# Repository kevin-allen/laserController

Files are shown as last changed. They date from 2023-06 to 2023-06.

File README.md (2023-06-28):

# laserController

This repository describes our setup used to perform optogenetic stimulation in behavioral experiments. 

The laser pulses are controlled using a Python script and a TTL signal delivered from an Arduino Uno.

## Material needed

* Arduino Uno
* Arduino Shield (see Eagle files)
* USB cable
* Ethernet cable
* Ethernet socket for the Arduino shield
* Laser head ()
* Laser power ()
* ...

## Arduino shield

The Eagle files of the Arduino sheild are in the folder eagleFiles. You can use these files to generate Gerber files and order the shield from EuroCircuits.
The shield has one Ethernet cable that goes to the laser power box. There are 2 BNC sockets that can be used to send the TTL and power signal to the recording system. The signal will range from 0 to 5V so make sure that the hardware accepting these signals can cope with a 5V signal.

## Installation steps

Ethernet socket:
* pin 2: analog input, set power (0 to 5V defines the ratio of maximum power as defined using the manual poti)
* pin 3: pulse on/off (TTL)
* pin 4 & 5: connect together, apply HIGH for ON, apply LOW for OFF, don't apply any voltage there: key will turn on/off
* pin 6: ground

# Laser controller ROS

These *topics* are subscribed to by the Arduino connected to the Laser controller.

 *   `laser_enable`: bool enabled/disabled
 *   `laser_power`: byte 0-255 relative power of max power set on controller
 *   `laser_pulselen_on`: pulse length [ms] = 1/(2*frequency),  
       duty cycle on [ms] = laser_pulselen_on / (laser_pulselen_on + laser_pulselen_off)
 *   `laser_pulselen_off`: pulse off time [ms], set 0 for constant on

The former (`laser_controller__pulse50dutycycle.old`) sketch only had fixed 50% duty cycle and `laser_pulselen` as corresponding ros topic.

# Usage example
 You can
 - use the example file `python_ros_example/control_laser.py` and set the power, pulse_len and duty_cycle , or
 - use rostopic to publish , see description like in `sketches/laser_controller_ros/laser_controller_ros.ino`
     *   enable: `rostopic pub -1 /laser_enable std_msgs/Bool 1`
     *   set power: `rostopic pub -1 /laser_power std_msgs/UInt8 200`
     *   set pulse len on duration: `rostopic pub -1 /laser_pulselen_on std_msgs/UInt32 5`
     *   set pulse len off duration: `rostopic pub -1 /laser_pulselen_off std_msgs/UInt32 95`

# pulse length, frequency and duty cycle
- $t_\mathrm{on}$: pulse len on duration
- $t_\mathrm{off}$: pulse len off duration
- $T=t_\mathrm{on}+t_\mathrm{off}$: period duration
- $f=\frac{1}{T}$: frequency
- $d = \frac{t_\mathrm{on}}{T}$: duty cycle ( $0 < d \leq 1$ ), <sup><sub>The case `d=1` is treated individually and handled without timers.</sub></sup>

example ( [paper](https://pubmed.ncbi.nlm.nih.gov/35584671/) ):
"stimulation at 10 Hz with a 5 ms duration "
- $f=10\mathrm{Hz},\ T=100\mathrm{ms},\ t_\mathrm{on}=5\mathrm{ms},\ d=0.05$  (this example is acheived by above ros command)

Nota bene: The effective power (measured on average) will scale $\propto d$ as this is the raio of on duration.

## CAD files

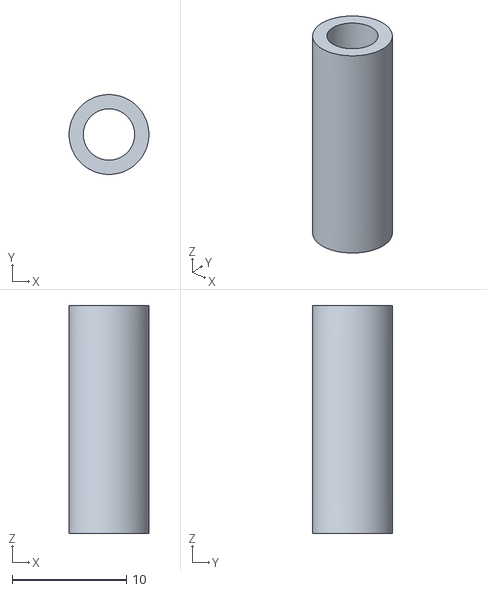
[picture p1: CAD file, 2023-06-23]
Actuator_marcel_edition/spacer.stl
7.00 x 7.00 x 20.0

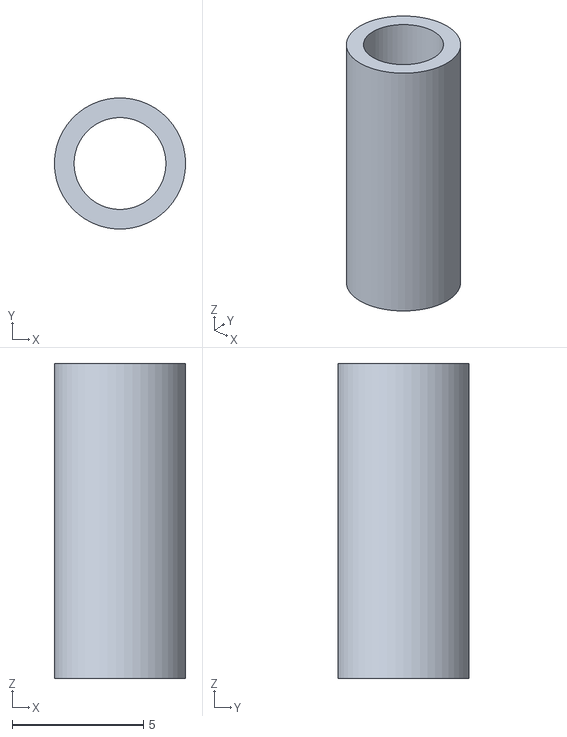
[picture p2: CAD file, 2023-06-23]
actuator_modified/spacer_platforms_12mm.stl
5.00 x 4.99 x 12.0

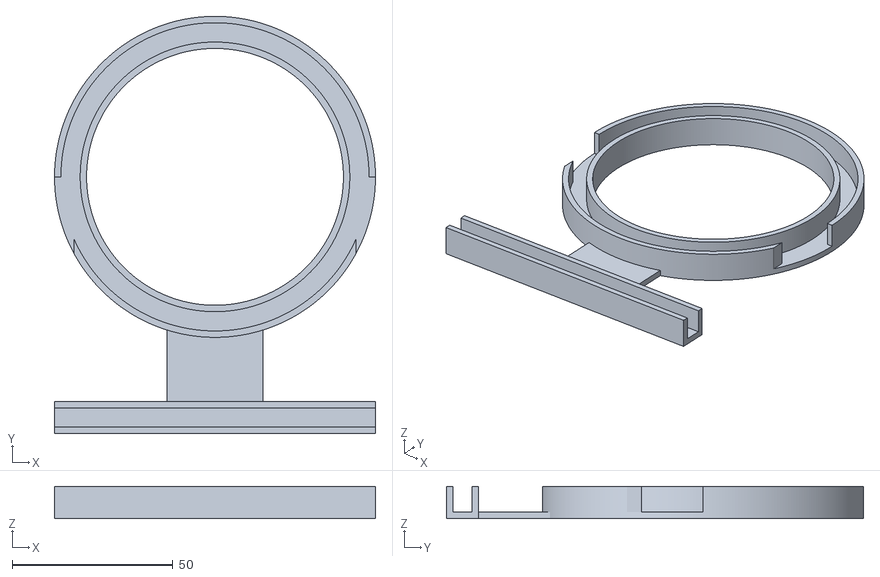
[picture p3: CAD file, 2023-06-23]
cad/splitter_holder_on_actuator.stl
100.0 x 130.0 x 10.0

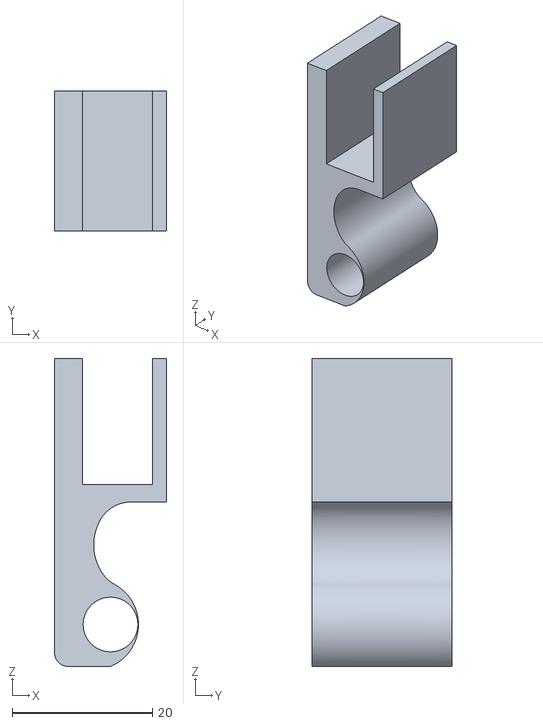
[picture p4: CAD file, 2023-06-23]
Actuator_marcel_edition/ChainHolder.stl
16.0 x 20.0 x 44.0

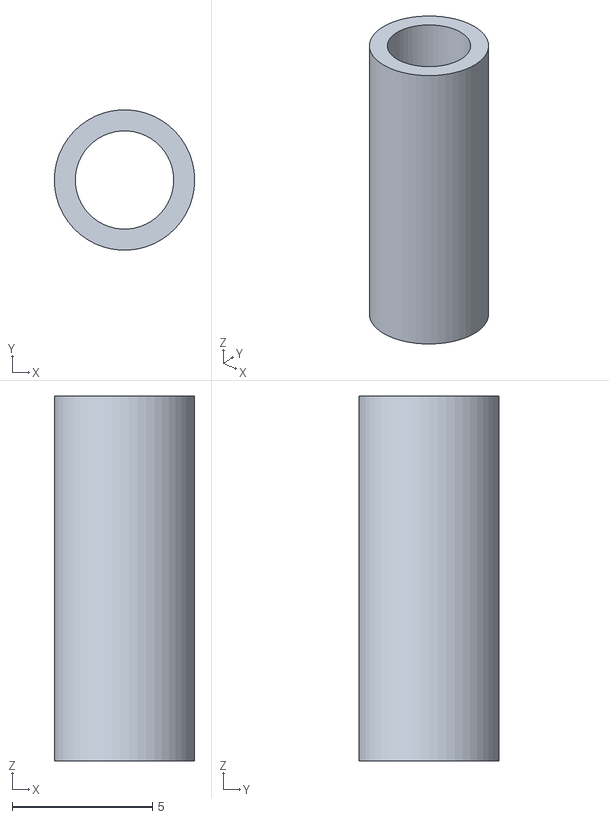
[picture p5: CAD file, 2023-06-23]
actuator_modified/spacer_platforms_13mm.stl
5.00 x 4.99 x 13.0

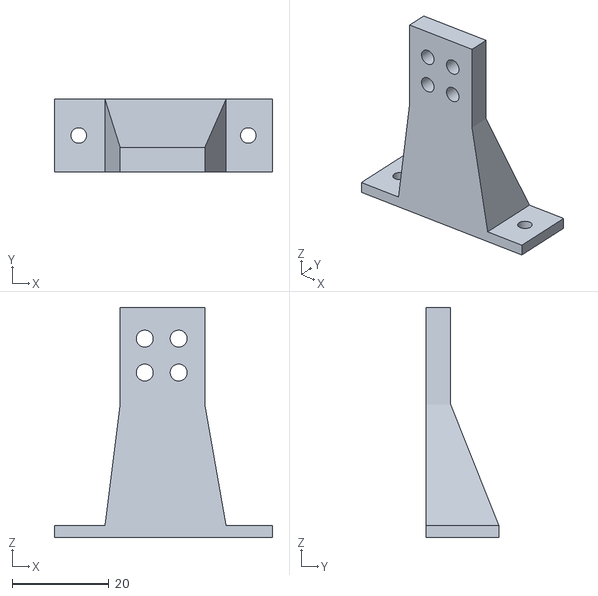
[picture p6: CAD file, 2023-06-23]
Actuator_marcel_edition/cable-management-attacher.stl
45.0 x 15.0 x 47.5

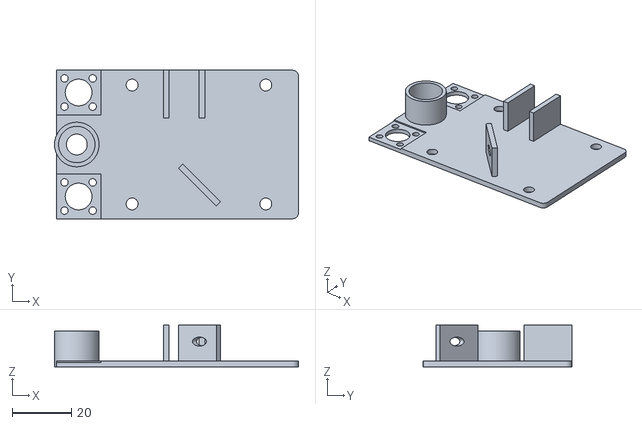
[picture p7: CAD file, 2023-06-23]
actuator_modified/middle_top_2_opto.stl
82.1 x 50.0 x 14.0

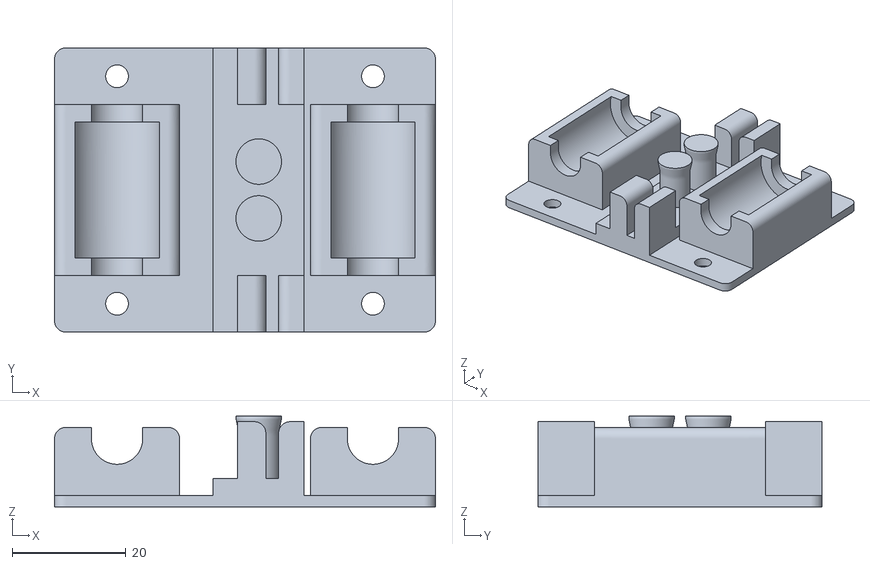
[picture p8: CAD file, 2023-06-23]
Actuator_marcel_edition/MiddleBottom.stl
67.0 x 50.0 x 16.0

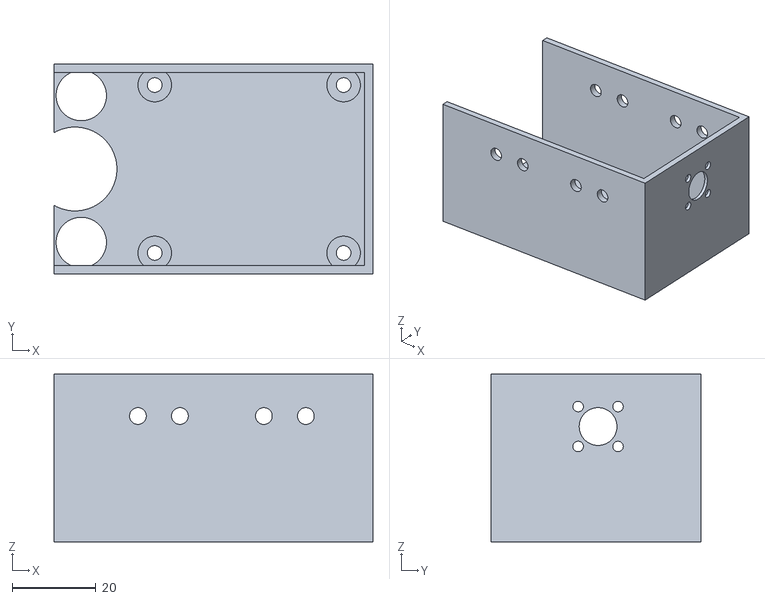
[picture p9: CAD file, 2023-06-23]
actuator_modified/top_opto_cable_organization_v2.stl
76.0 x 50.0 x 40.0

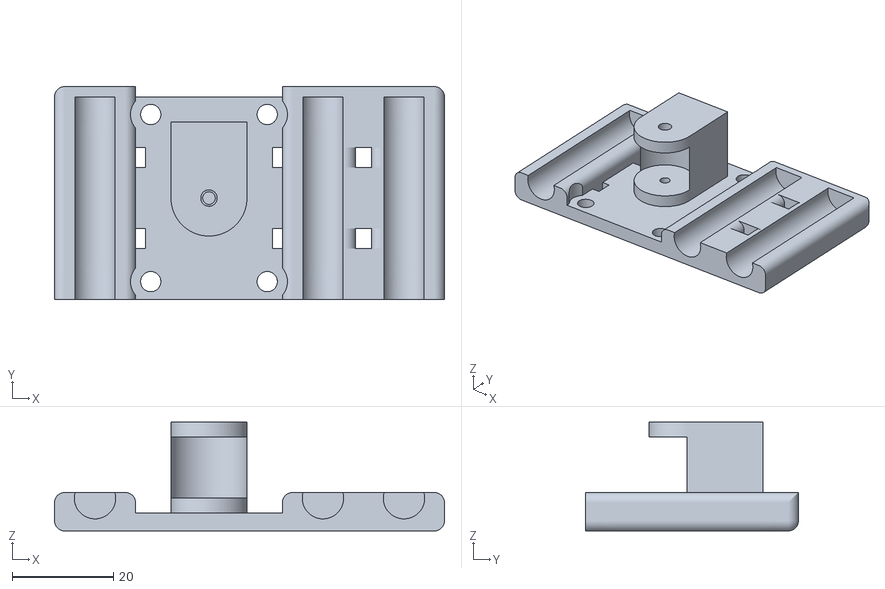
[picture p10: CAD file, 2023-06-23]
Actuator_marcel_edition/x_axis_Bearing.stl
77.0 x 42.0 x 21.5

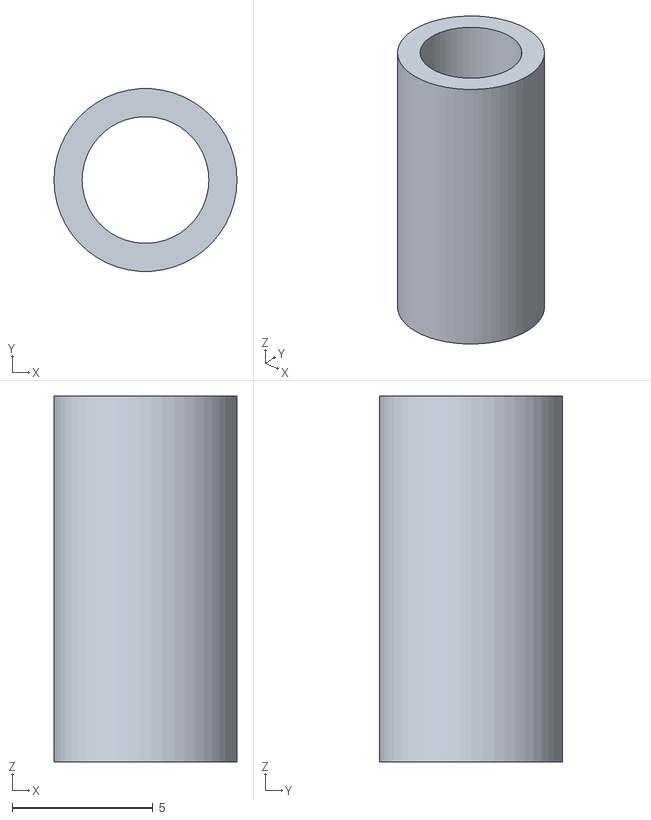
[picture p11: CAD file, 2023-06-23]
actuator_modified/spacer_platforms.stl
6.50 x 6.49 x 13.0

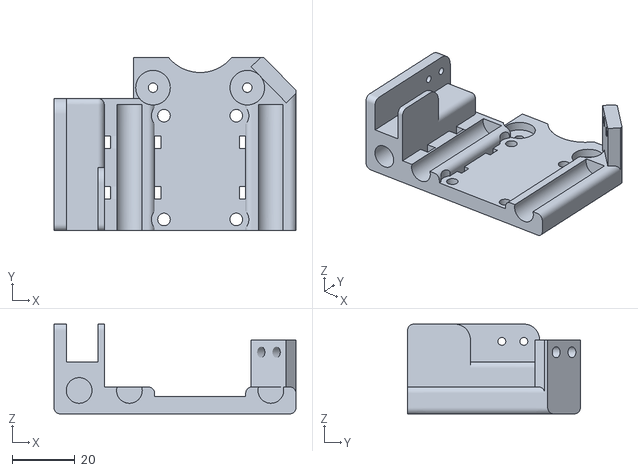
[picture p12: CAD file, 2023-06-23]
Actuator_marcel_edition/x_axis_Bearing_Motor.stl
77.0 x 55.0 x 28.6

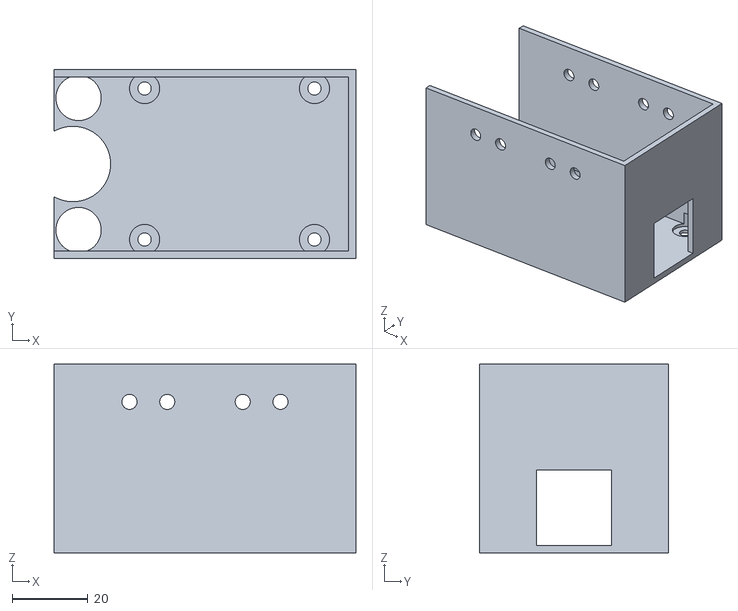
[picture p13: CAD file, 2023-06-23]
actuator_modified/top_opto_cable_organization.stl
80.0 x 50.0 x 50.0

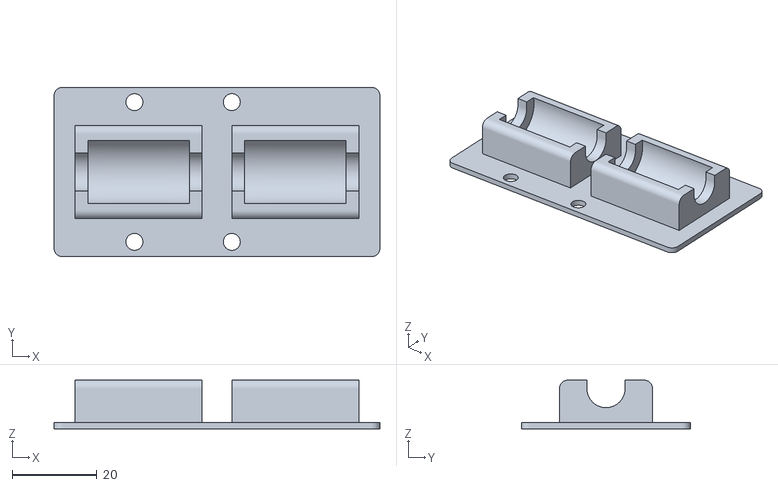
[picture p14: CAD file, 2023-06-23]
Actuator_marcel_edition/sliderPulley.stl
77.0 x 40.0 x 11.5

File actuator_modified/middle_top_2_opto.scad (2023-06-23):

$fn=50;


difference(){

    // main plate (import & add)
    
    union(){
        import("../Actuator_marcel_edition/MiddleTop.stl");

        translate([-48,-25,0])
            cube([17,21,2]);
        
        translate([-48,4,0])
            cube([17,21,2]);
        
        translate([-48,-4,0])
            cube([1,8,2]);
        
        
    }
    
    // remove space for opto laser socket
    
    translate([-48,-25,1.5])
        translate([7.5,7.5])
        opto_connector_neg();
    translate([-48,10,1.5])
        translate([7.5,7.5])
        opto_connector_neg();

}



module opto_connector_neg(){

diam=15;
translate([-diam/2,-diam/2,0])
cube([diam,diam,1]);
connectordiam = 9;

translate([0,0,-2])
cylinder(5,connectordiam/2,connectordiam/2);

screwdiam = 2.5;

delta=9.5; // inter hole distance 7.5 - 11.5
translate([0,0,-2])
for ( dx = [-1:2:1] ){
for ( dy = [-1:2:1] ){
translate([dx*delta/2,dy*delta/2])
cylinder(5,screwdiam/2,screwdiam/2);
}
}

}

/*
translate([-48,0,0])
cube([81.5,10,10]);
*/

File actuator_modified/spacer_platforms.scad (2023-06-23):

// spacer between layers on actuator platform for storing laser cable

$fn = 50;

// height: screw = 2cm
// platforms: 2mm each (2x bottom, 1x top)
// remaining height for nut: 2mm

h = 20-3*2 - 2;

h=13; // set manually
echo("h=",h);

innerdiam = 4.5;
outerdiam = 6.5;

difference(){
    cylinder(h,outerdiam/2,outerdiam/2);
    cylinder(h,innerdiam/2,innerdiam/2);
}

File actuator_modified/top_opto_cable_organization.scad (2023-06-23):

// top mount for laser cable organization

$fn = 50;


wall_height = 50;
wall_thick = 2;
//translate([-47.5,-25,20])

module opto_connector_neg(){

diam=15;
translate([-diam/2,-diam/2,0])
cube([diam,diam,1]);
connectordiam = 9;

translate([0,0,-2])
cylinder(5,connectordiam/2,connectordiam/2);

screwdiam = 2.5;

delta=9.5; // inter hole distance 7.5 - 11.5
translate([0,0,-2])
for ( dx = [-1:2:1] ){
for ( dy = [-1:2:1] ){
translate([dx*delta/2,dy*delta/2])
cylinder(5,screwdiam/2,screwdiam/2);
}
}

}

difference(){
    // main plate and walls
    union(){
        cube([80,50,2]);
        
        cube([80,wall_thick,wall_height]);
        translate([0,50-wall_thick,0]) cube([80,wall_thick,wall_height]);
        translate([80-wall_thick,0,0]) cube([wall_thick,50,wall_height]);
    }
    
    // inser wjole for the cables
    //translate([78,15,2])
    //cube([2,20,20]);
    
    // have another opto cable connector:
    
    
    translate([20,50,40])    rotate([90,0,0])    cylinder(99,2,2);
    translate([30,50,40])    rotate([90,0,0])    cylinder(99,2,2);
    translate([50,50,40])    rotate([90,0,0])    cylinder(99,2,2);
    translate([60,50,40])    rotate([90,0,0])    cylinder(99,2,2);
    
    
    // space for commutator
    translate([5,25,0])
        cylinder(5,10,10);
    
    // opto 1
    translate([6.5,7.5,0])
        cylinder(5,6,6);
    //translate([0,7,0])
    //    cube([8,1,2]);
    
    // opto 2
    translate([6.5,50-7.5,0])
        cylinder(5,6,6);
    //translate([0,50-7-1,0])
    //    cube([8,1,2]);
    
    // 4 screw holes
    translate([80-11,5,0])
        cylinder(5,3.5/2,3.5/2);
    translate([80-11,50-5,0])
        cylinder(5,3.5/2,3.5/2);
    translate([80-11-45,5,0])
        cylinder(5,3.5/2,3.5/2);
    translate([80-11-45,50-5,0])
        cylinder(5,3.5/2,3.5/2);
    
    // 4 nuts recessed
    translate([80-11,5,1])
        cylinder(5,8/2,8/2);
    translate([80-11,50-5,1])
        cylinder(5,8/2,8/2);
    translate([80-11-45,5,1])
        cylinder(5,8/2,8/2);
    translate([80-11-45,50-5,1])
        cylinder(5,8/2,8/2);    
    
}

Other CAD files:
Actuator_marcel_edition/sliderBelt.stl
Actuator_marcel_edition/MiddleTop.stl
actuator_modified/top_opto_cable_organization_v2.scad
cad/splitter_holder_on_actuator.scad
cad/splitter_holder_on_actuator_v3.scad
cad/splitter_holder_on_actuator_v5.scad

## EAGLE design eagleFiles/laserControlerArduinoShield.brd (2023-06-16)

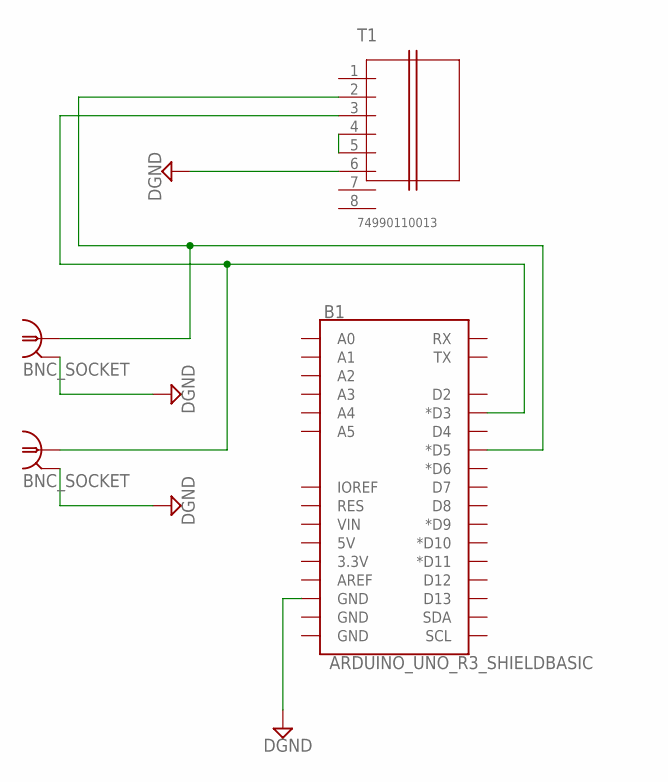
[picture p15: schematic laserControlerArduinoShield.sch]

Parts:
B1: ARDUINO_UNO_R3_SHIELDBASIC; UNO_R3_SHIELD
BNC_POWER: BNC_SOCKET
BNC_TTL: BNC_SOCKET
T1: 74990110013; 01LAN_RJ45_10/00_STD

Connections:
DGND: B1.GND@2 (GND), BNC_POWER.P$1 (2), BNC_POWER.P$2 (2), BNC_POWER.P$3 (2), BNC_POWER.P$4 (2), BNC_TTL.P$1 (2), BNC_TTL.P$2 (2), BNC_TTL.P$3 (2), BNC_TTL.P$4 (2), T1.6
unnamed: B1.D5 (*D5), BNC_TTL.P$SIGNAL (1), T1.2
unnamed: B1.D3 (*D3), BNC_POWER.P$SIGNAL (1), T1.3
unnamed: T1.4, T1.5

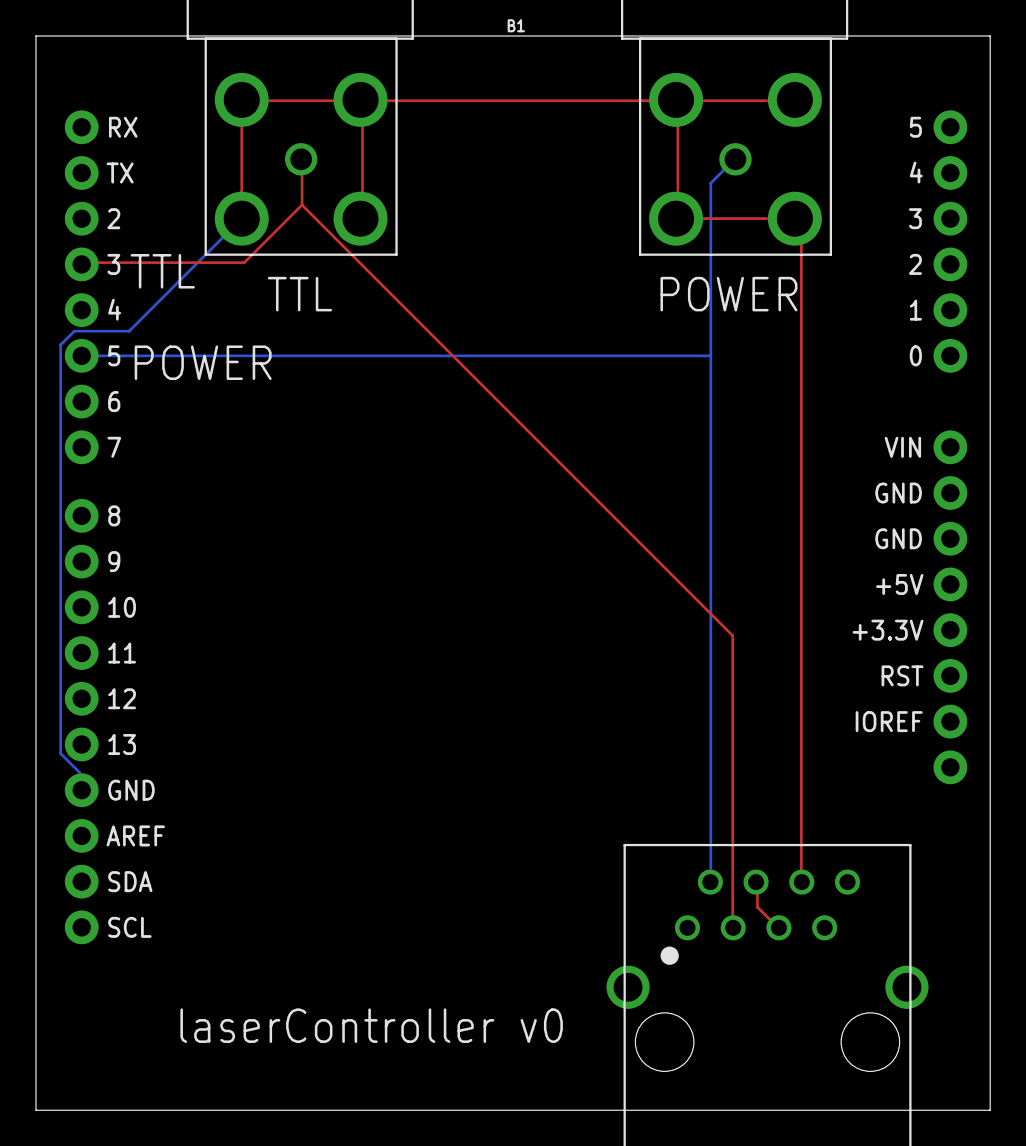
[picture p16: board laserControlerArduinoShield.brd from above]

Board: 2 copper layers, 53.0 x 59.7 mm, 4 parts (0 on the bottom side), 4 nets.

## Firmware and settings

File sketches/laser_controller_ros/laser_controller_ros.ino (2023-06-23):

/* 
 *  Laser controller
 *  ROS node
 *  
 *  for CrystaLaser CL-2005 laser power supply
 *  https://neurophysics.ucsd.edu/Manuals/CrystaLaser/Diode%20Pumped%20Solid%20State%20CrystaLaser.pdf
 *
 *
 * Pascal
 * 14/06/2023 - 15/06/2023
 * 
 * 
 * topics: 
 *   laser_enable: bool enabled/disabled
 *   laser_power: byte 0-255 relative power of max power set on controller
 *   laser_pulselen_on: pulse length [ms] = 1/(2*frequency), duty cycle on [ms] = laser_pulselen_on / (laser_pulselen_on + laser_pulselen_off)
 *   laser_pulselen_off: pulse off time [ms], set 0 for constant on
 * (could have a topic laser_pulselen to set both to the same time, that is duty cycle = 50%)
 *
 * running on  
 *   /dev/serial/by-id/usb-Arduino__www.arduino.cc__0043_9513731393235111C1A1-if00
 * 
 * commands:
 *   roscore
 *   rosrun rosserial_python serial_node.py /dev/serial/by-id/usb-Arduino__www.arduino.cc__0043_9513731393235111C1A1-if00 __name:=node_lasercontroller
 *   rostopic pub -1 /laser_enable std_msgs/Bool 1
 *   rostopic pub -1 /laser_power std_msgs/UInt8 123
 *   rostopic pub -1 /laser_pulselen std_msgs/UInt32 99
 *
 */

// ROS includes with messages for topics
#include <ros.h>
#include <std_msgs/Bool.h>
#include <std_msgs/UInt8.h>
#include <std_msgs/UInt32.h>

// PINOUT
//  PIN 13 pulse: on/off based on frequency
//  Pin  3 power: analog output (ratio of max power)
//  connect interlock
#define PIN_PULSE 13
#define PIN_POWER 3

// laser pulse sending
unsigned long time_last_pulse_on = 0;
unsigned long time_last_pulse_off = 0;
unsigned long time_now;

// laser parameters
bool laser_enabled = false;
uint32_t laser_pulselen_on = 500;
uint32_t laser_pulselen_off = 500;
bool laser_state = false;
bool constant_on = false;


// === ROS ===
ros::NodeHandle nh;

// callback functions for the topics

// callback for topic "laser_enable"
void cb_LaserEnable(const std_msgs::Bool& msg){
  nh.loginfo("callback laser enable");
  bool x = msg.data;
  laser_enabled = x;
  
  if (laser_enabled){
    // start laser and sync to now time, so that loop() will continue with correct time length
    digitalWrite(PIN_PULSE, HIGH);
    laser_state = true;
    time_last_pulse_on = millis();
    nh.loginfo("enable");
  }
  else {
    // disable, directly shut down
    digitalWrite(PIN_PULSE, LOW);
    nh.loginfo("disable");
  }
}

// callback for topic "laser_power"
void cb_LaserPower(const std_msgs::UInt8& msg){
  nh.loginfo("callback laser power");
  uint8_t x = msg.data;
  analogWrite(PIN_POWER, x); // set laser power as defined by ros message
}

// callback for topic "laser_pulselen_on"
void cb_LaserPulselenOn(const std_msgs::UInt32& msg){
  nh.loginfo("callback laser pulselen on");
  uint32_t x = msg.data;
  
  laser_pulselen_on = x;
  nh.loginfo("set pulse len"); 
}

// callback for topic "laser_pulselen_off"
void cb_LaserPulselenOff(const std_msgs::UInt32& msg){
  nh.loginfo("callback laser pulselen off");
  uint32_t x = msg.data;
  
  if (x == 0){
    constant_on = true;
    nh.loginfo("constant on");
  }
  else {
    constant_on = false;
    laser_pulselen_off = x;
    nh.loginfo("set pulse len");
  }
}

// subscribers for the topics
ros::Subscriber<std_msgs::Bool> subLaserEnable("laser_enable", &cb_LaserEnable);
ros::Subscriber<std_msgs::UInt8> subLaserPower("laser_power", &cb_LaserPower);
ros::Subscriber<std_msgs::UInt32> subLaserPulselenOn("laser_pulselen_on", &cb_LaserPulselenOn);
ros::Subscriber<std_msgs::UInt32> subLaserPulselenOff("laser_pulselen_off", &cb_LaserPulselenOff);


// INITIALIZE

void setup()
{
  pinMode(PIN_PULSE, OUTPUT);
  pinMode(PIN_POWER, OUTPUT);
  digitalWrite(PIN_PULSE, LOW);
  digitalWrite(PIN_POWER, LOW);

  nh.initNode();
  nh.subscribe(subLaserEnable);
  nh.subscribe(subLaserPower);
  nh.subscribe(subLaserPulselenOn);
  nh.subscribe(subLaserPulselenOff);

  delay(500);
  nh.loginfo(" === Arduino Laser Controller === ");
}

void loop()
{
  // ROS handling
  nh.spinOnce();
  delay(1);

  // Laser pulses handling
  time_now = millis();
  if (laser_enabled){
    if (constant_on){
      digitalWrite(PIN_PULSE, HIGH);
    }
    else
    {
      if (time_now-time_last_pulse_on > laser_pulselen_on && laser_state==HIGH){
        laser_state = LOW;
        digitalWrite(PIN_PULSE, laser_state);
        time_last_pulse_off = time_now;
      }
      if (time_now-time_last_pulse_off > laser_pulselen_off && laser_state==LOW){
        laser_state = HIGH;
        digitalWrite(PIN_PULSE, laser_state);
        time_last_pulse_on = time_now;
      }
    }
  }

}

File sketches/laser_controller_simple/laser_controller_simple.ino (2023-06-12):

const int laserPin = 13; // Digital pin connected to the laser

void setup() {
  pinMode(laserPin, OUTPUT); // Set the laser pin as an output
}

void loop() {
  digitalWrite(laserPin, HIGH); // Turn on the laser
  delay(10); // Wait for 10 ms

  digitalWrite(laserPin, LOW); // Turn off the laser
  delay(100); // Wait for 100 ms 
}

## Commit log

2023-06-12 eagle sketch
    [laserControlerArduinoShield.brd, laserControlerArduinoShield.sch]
2023-06-14 connect pins 4-5 in ethernet connector to turn the laser on
    [laserControlerArduinoShield.brd, laserControlerArduinoShield.sch]
2023-06-16 add bnc connectors to arduino shield to sent ttl to recording system
    [laserControlerArduinoShield.brd, laserControlerArduinoShield.sch]
2023-06-16 Arduino ros sketch, example python script, update documentation
2023-06-16 add AutoPI laser prog
2023-06-23 openscad part to hold the beam splitter
    [splitter_holder_on_actuator.scad, splitter_holder_on_actuator.stl]
2023-06-26 new actuator top with part to hold the optic fiber
    [splitter_holder_on_actuator_v3.scad]
2023-06-26 Add files via upload
    add the optic connector holder for the splitter
    [splitter_holder_on_actuator_v5.scad]
2023-06-28 Update README.md
    explanation on power measured on average

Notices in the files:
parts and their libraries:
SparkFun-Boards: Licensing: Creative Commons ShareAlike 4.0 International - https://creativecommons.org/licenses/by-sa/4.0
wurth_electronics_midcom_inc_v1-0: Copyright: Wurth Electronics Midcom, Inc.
